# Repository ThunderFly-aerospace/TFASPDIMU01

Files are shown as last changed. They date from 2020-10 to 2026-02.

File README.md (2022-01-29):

# TFASPDIMU01 - sdp3x differental pressure sensor and IMU 9-axis unit



ThunderFly TFASPDIMU01 is SPI/I2C sensor board equipped with a differential pressure sensor (Senserion [SDP3x](https://www.sensirion.com/sdp3x/)) and 9-axis motion tracking sensor ([ICM-20948](https://invensense.tdk.com/products/motion-tracking/9-axis/icm-20948/)). Board is equipped with 7pin JST-GH connector. The sensor board is designed for multiple uses. It can be used as a self-adjusting anemometer [WINDGAUGE03](https://github.com/mlab-modules/WINDGAUGE03) or as an airspeed sensor for UAVs with optional function as the external magnetometer.

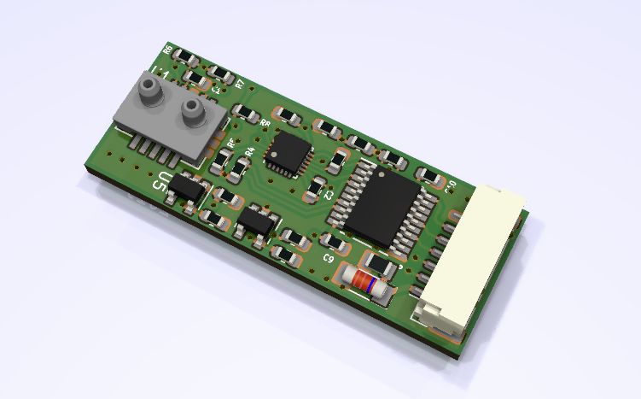
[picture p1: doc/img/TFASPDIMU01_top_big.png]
TFASPDIMU01 PCB


TFASPDIMU is commercially available from [ThunderFly s.r.o.](https://www.thunderfly.cz/), write an email to info@thunderfly.cz or shop at [Tindie store](https://www.tindie.com/stores/thunderfly/).

## Specification
 * Type: Differential and 9-axis motion sensor board
 * Mass: 3 g
 * Size: 36 x 14 mm
 * Power: +5 V
 * Connection: 7pin JST-GH connector, custom pinout

**SDP3x**
 * Range: +/- 125/500 Pa (depending on exact sensor type)
 * Excellent accuracy and repeatability, even below one Pascal
 * No zero-point offset, no temperature drift
 * Calibrated and temperature compensated
 * Fast sampling time of 2kHz at 16 bit resolution
 * I2C address: 0x21 (d33)

 **ICM-20948**
 * 3-axis gyroscope, 3-axis accelerometer, 3-axis compass (magnetometer)
 * Onboard Digital Motion Processor (DMP)
 * On-Chip 16-bit ADCs and Programmable Filters
 * 7 MHz SPI or 400 kHz Fast Mode I²C
 * Digital temperature sensor
 * Default I2C address: 0x68 (0d104), can be changed to 0x69 (0d105) by moving the resistor R2->R1. 

## Example of uses

### WINDGUAGE01

Ground control station anemometer [WINDGAUGE03](https://github.com/mlab-modules/WINDGAUGE03)

### TFSLOT01 - UAV airspeed sensor

Our [TFSLOT](https://github.com/ThunderFly-aerospace/TFSLOT01) senzor is an airspeed sensor for use mainly on UAV. Due to 3D printed case it is possible to optimalize part according to the location of sensor on UAV and tune their characteristics. First use of this sensor was on our autogyro [TF-G2](https://github.com/ThunderFly-aerospace/TF-G2/).

TFSLOT01 sensor

More details about this solution is available in the repository [TFSLOT01](https://github.com/ThunderFly-aerospace/TFSLOT01).

### TFPIPE01 - UAV airspeed sensor

Symmetric variant of TFSLOT sensor for different mounting options [TFPIPE01](https://github.com/ThunderFly-aerospace/TFPIPE01).

### TFVENTUFO - omnidirectional anemometer
This anemometer should also based on venturi effect. Thanks to an clever design, it will measure the wind speed from all directions (without knowing the direction).

### Angle of Attack sensor

In case of mounting on rotation slip-ring bearing the sensor could sense air [AoA of the vehicle](https://en.wikipedia.org/wiki/Angle_of_attack). Due to ability to turn in direction of airflow. The turnig direction could be sensed differentialy to position of aircraft by IMU embedded in the TFASPDIMU01 sensor. 

## Hardware

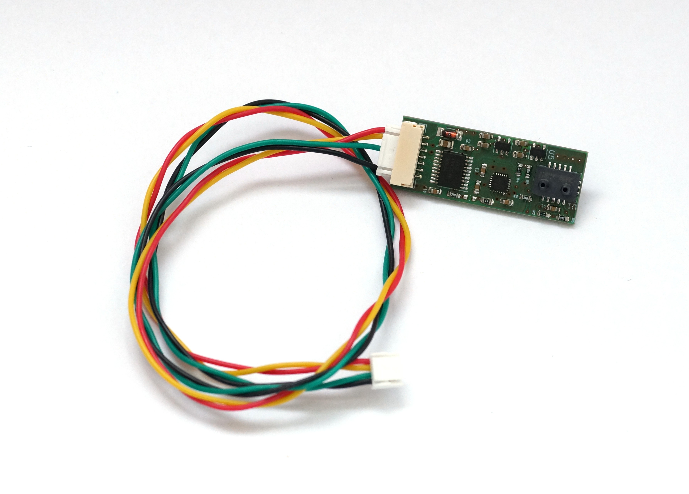
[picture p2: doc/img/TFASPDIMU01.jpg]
TFASPDIMU01 sensor


### Eletronic schema

Full schema is avialible in [PDF](/hw/sch_pcb/TFASPDIMU01.pdf)
schema

### Hardware layout

** IMG - technical draft **

### Pinout
|Pin #| I2C | SPI  |
| --- |:---:|:----:|
| 1 | +5V | +5V  |
| 2 | SCL | SCK  |
| 3 | --  | MISO |
| 4 | SDA | MOSI |
| 5 | --  | CS |
| 6 | INT | INT  |
| 7 | GND | GND  |
> Due to the possible wider use of the sensor, a standard pixhawk pinout is not used.

#### PixHawk autopilot cable

To increase the transmission quality, it is recommended to create pairs SDA,GND and SCL,+5V on the cable (as shown in image)

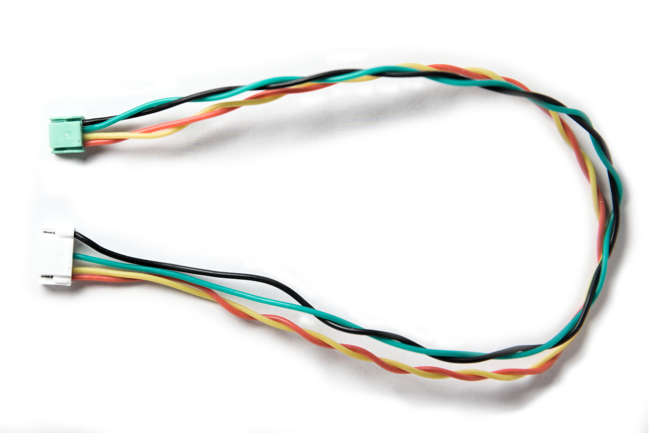
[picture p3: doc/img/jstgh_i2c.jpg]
I2C jstgh


| TFASPDIMU01 Pin | Sigal | Pixhawk | Color |
| ---:|:-----:|:---:|---|
| 1 | +5V |  1 | Red |
| 2 | SCL |  2 | Yellow|
| 4 | SDA |  3 | Green |
| 7 | GND |  4 | Black |
> Pixhawk pinout is listed according to the [Pixhawk connector standard](https://github.com/pixhawk/Pixhawk-Standards/blob/master/DS-009%20Pixhawk%20Connector%20Standard.pdf).

## Usage

### Python
For reading data from the sensor, we have prepared a python script in PyMLAB library that uses the pySMBus to readout data. It can be used directly from a computer with a corresponding converter (for example MLAB [USBI2C01A](https://wiki.mlab.cz/doku.php?id=cs:usbi2c)) or with one-board computers (Odroid, raspberry and similar) that have own smbus output.

#### Calibration vertification
Calibration can be verified by mounting of an anemometer to car roof and comparing it to speed obtained from GPS (gpsd). This needs to be done in windless weather.

### PX4
> We are now working on implementation of driver into PX4 stack.

Main usage of this sensor is as airspeed sensor. It can be also used as an external magnetometer and thermometer.

### Ardupilot
We are currently unable to implement the sensor in the Ardupilot flight stack. However, we will be happy to provide assistance with implementation. You can [contact us](https://www.thunderfly.cz/contact-us.html)

#### configuration
*TODO*

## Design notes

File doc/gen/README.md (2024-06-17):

# PCB

Board size: 36.0x14.0 mm (1.42x0.55 inches)

- This is the size of the rectangle that contains the board
- Thickness: 1.6 mm (63 mils)
- Material: FR4
- Finish: HAL
- Layers: 2
- Copper thickness: 35 µm

Solder mask: TOP / BOTTOM

- Color: Green

Silk screen: TOP / BOTTOM

- Color: White

# Important sizes

Clearance: 0.2 mm (8 mils)

Track width: 0.2 mm (8 mils)

- By design rules: 0.2 mm (8 mils)

Drill: 0.5 mm (20 mils)

- Vias: 0.5 mm (20 mils) [Design: 0.4 mm (16 mils)]
- Pads: 0.7 mm (28 mils)
- The above values are real drill sizes, they add 0.1 mm (4 mils) to plated holes (PTH)

Via: 0.8/0.4 mm (31/16 mils)

- By design rules: 0.8/0.3 mm (31/12 mils)
- Micro via: yes [0.2/0.1 mm (8/4 mils)]
- Buried/blind via: yes
- Total: 59 (thru: 59 buried/blind: 0 micro: 0)

Outer Annular Ring: 0.15 mm (6 mils)

- By design rules: 0.15 mm (6 mils)

Eurocircuits class: 4B
- Using min drill 0.5 mm for an OAR of 0.15 mm

# General stats

Components count: (SMD/THT)

- Top: 25/1 (SMD + THT)
- Bottom: 0/0 (NONE)

Defined tracks:

- 0.2 mm (8 mils)
- 0.25 mm (10 mils)
- 0.3 mm (12 mils)
- 0.4 mm (16 mils)
- 0.5 mm (20 mils)
- 0.6 mm (24 mils)
- 0.7 mm (28 mils)
- 0.8 mm (31 mils)

Used tracks:

- 0.2 mm (8 mils) (136) defined: yes
- 0.25 mm (10 mils) (72) defined: yes
- 0.3 mm (12 mils) (80) defined: yes
- 0.5 mm (20 mils) (53) defined: yes
- 0.6 mm (24 mils) (3) defined: yes

Defined vias:

- 0.8/0.4 mm (31/16 mils)

Used vias:

- 0.8/0.4 mm (31/16 mils) (Count: 59, Aspect: 2.0 A) defined: yes

Holes (excluding vias):

- 0.7 mm (28 mils) (3)

Oval holes:

Drill tools (including vias and computing adjusts and rounding):

- 0.5 mm (20 mils) (59)
- 0.7 mm (28 mils) (3)

Solder paste stats:

Using a paste with 87.75 % alloy, that has an specific gravity for the alloy of 7.4 g/cm³
and 1.0 g/cm³ for the flux. This paste has an specific gravity of  4.15 g/cm³.

The stencil thickness is  0.12 mm.

| Side | Pads with paste | Area [mm²] | Paste [g] |
|---|---|---|---|
| Total  | 121 | 89.25 | 0.44 |

Note: this is just an approximation to the theoretical value. Margins of the solder mask and waste aren't computed.

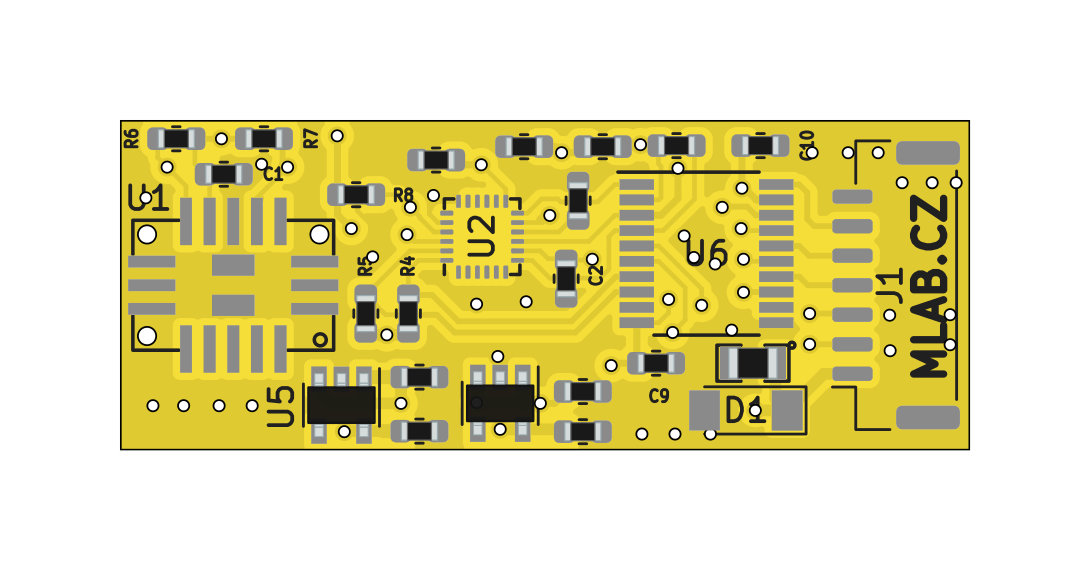
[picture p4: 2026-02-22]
doc/gen/img/TFASPDIMU01-top.png

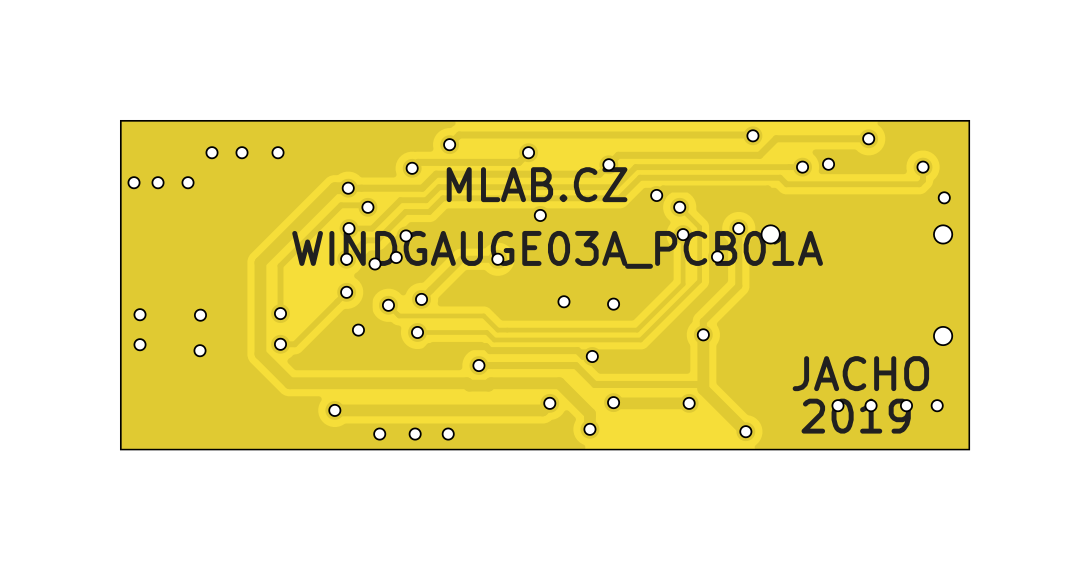
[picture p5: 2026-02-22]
doc/gen/img/TFASPDIMU01-bottom.png

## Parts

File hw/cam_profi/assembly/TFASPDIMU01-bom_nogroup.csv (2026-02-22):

Component | Description | Part | References | Value | Footprint | Quantity Per PCB | Datasheet | ust_id
1 | Unpolarized capacitor | C | C1 | 100nF | SMD-0603 | 1 | ~ | 5c70984712875079b91f8b4c
2 | Unpolarized capacitor | C | C10 | 100nF | SMD-0603 | 1 | ~ | 5c70984712875079b91f8b4c
3 | Unpolarized capacitor | C | C2 | 100nF | SMD-0603 | 1 | ~ | 5c70984712875079b91f8b4c
4 | Unpolarized capacitor | C | C3 | 100nF | SMD-0603 | 1 | ~ | 5c70984712875079b91f8b4c
5 | Unpolarized capacitor | C | C4 | 100nF | SMD-0603 | 1 | ~ | 5c70984712875079b91f8b4c
6 | Unpolarized capacitor | C | C9 | 100nF | SMD-0603 | 1 | ~ | 5c70984712875079b91f8b4c
7 | Unpolarized capacitor | C | C5 | 1uF | SMD-0603 | 1 | ~ | 5c70984712875079b91f8b50
8 | Unpolarized capacitor | C | C6 | 1uF | SMD-0603 | 1 | ~ | 5c70984712875079b91f8b50
9 | Unpolarized capacitor | C | C7 | 1uF | SMD-0603 | 1 | ~ | 5c70984712875079b91f8b50
10 | Unpolarized capacitor | C | C8 | 1uF | SMD-0603 | 1 | ~ | 5c70984712875079b91f8b50
11 | Unpolarized capacitor | C | C11 | 10uF | SMD-0805 | 1 | ~ | 5c70984812875079b91f8bbd
12 | Diode | D | D1 | BZV55C-5,6V | D_MiniMELF | 1 | ~ | 5c70984512875079b91f88b1
13 | 1x08 2.54 mm pitch header | SM07B-GHS-TB | J1 | SM07B-GHS-TB | JST_GH_SM07B-GHS-TB_1x07-1MP_P1.25mm_Horizontal | 1 |  | 5c7250081287500b4e112e78
14 | Resistor | R | R2 | 0R | SMD-0603 | 1 | ~ | 5c70984512875079b91f896b
15 | Resistor | R | R4 | 10k | SMD-0603 | 1 | ~ | 5c70984612875079b91f899f
16 | Resistor | R | R5 | 10k | SMD-0603 | 1 | ~ | 5c70984612875079b91f899f
17 | Resistor | R | R6 | 10k | SMD-0603 | 1 | ~ | 5c70984612875079b91f899f
18 | Resistor | R | R7 | 10k | SMD-0603 | 1 | ~ | 5c70984612875079b91f899f
19 | Resistor | R | R8 | 10k | SMD-0603 | 1 | ~ | 5c70984612875079b91f899f
20 | Resistor | R | R9 | 10k | SMD-0603 | 1 | ~ | 5c70984612875079b91f899f
21 | Resistor | R | R1 | - | SMD-0603 | 1 | ~
22 | InvenSense 9-Axis Motion Sensor, Accelerometer, Gyroscope, Compass, I2C/SPI, QFN-24 | ICM-20948 | U2 | ICM-20948 | InvenSense_QFN-24_3x3mm_P0.4mm | 1 | http://www.invensense.com/wp-content/uploads/2016/06/DS-000189-ICM-20948-v1.3.pdf | 5c725a431287500b4e112ef5
23 | 300mA Low-dropout Voltage Regulator, Vout 1.8V, Vin up to 5.5V, SOT-23 | MIC5504-1.8YM5 | U5 | MIC5504-1.8YM5-TR | SOT-23-5 | 1 | http://ww1.microchip.com/downloads/en/DeviceDoc/MIC550X.pdf | 5c7256781287500b4e112eba
24 | 300mA Low-dropout Voltage Regulator, Vout 3.3V, Vin up to 5.5V, SOT-23 | MIC5504-3.3YM5 | U4 | MIC5504-3.3YM5-TR | SOT-23-5 | 1 | http://ww1.microchip.com/downloads/en/DeviceDoc/MIC550X.pdf | 5c7255e81287500b4e112ea2
25 |  | SDP3x | U1 | SDP3x | SDP3x | 1 |  | 5c70984812875079b91f8bd0
26 | Bidirectional level-shifting voltage translator, TSSOP-20 | TXS0108EPW | U6 | TXS0108EPW | TSSOP-20_4.4x6.5mm_P0.65mm | 1 | www.ti.com/lit/ds/symlink/txs0108e.pdf | 5c7258471287500b4e112edd

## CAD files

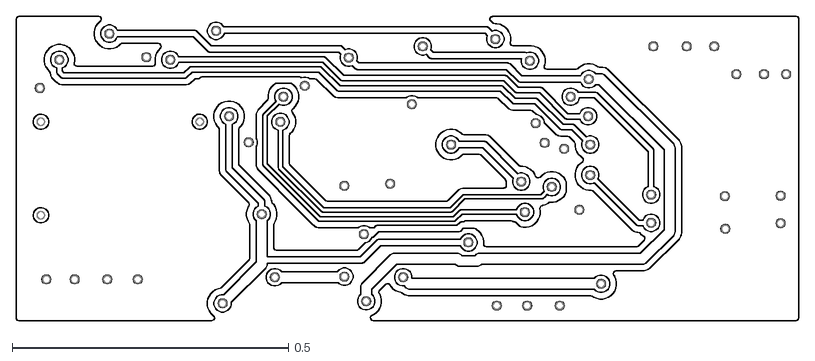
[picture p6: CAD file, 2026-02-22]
doc/gen/dxf/TFASPDIMU01-B_Cu.dxf
1.42 x 0.55

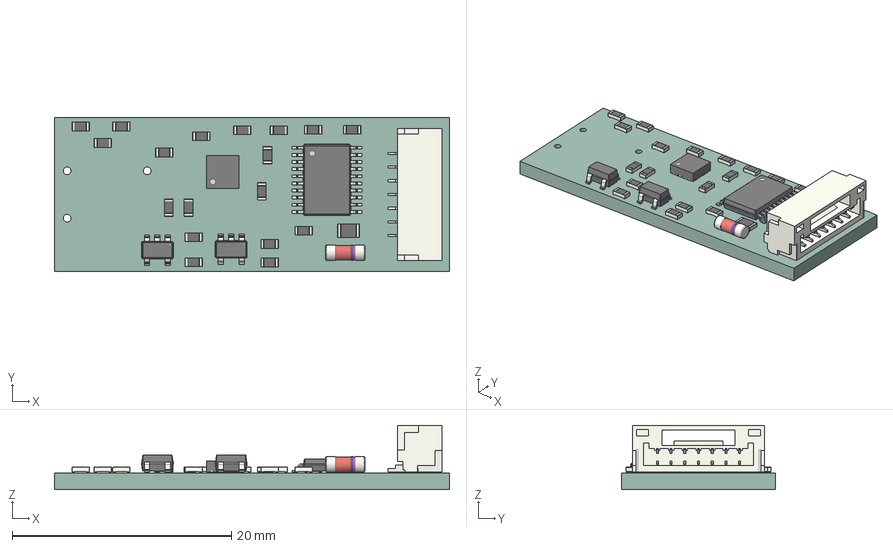
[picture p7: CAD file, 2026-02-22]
doc/gen/TFASPDIMU01.step
36.0 x 14.0 x 5.84 mm
R_0603_1608Metric x 18
QFN-24-1EP_3x3mm_P0.4mm_EP1.75x1.6mm
D_MiniMELF
TSSOP-20_4.4x6.5mm_P0.65mm
JST_GH_SM07B-GHS-TB_1x07-1MP_P1.25mm_Horizontal
SOT-23-5 x 2
R_0805_2012Metric
kibot_vu3v6cgv_PCB

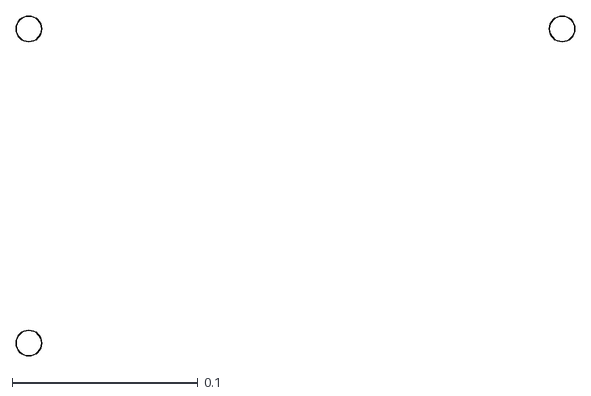
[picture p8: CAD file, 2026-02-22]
doc/gen/dxf/TFASPDIMU01-B_Courtyard.dxf
0.301 x 0.183

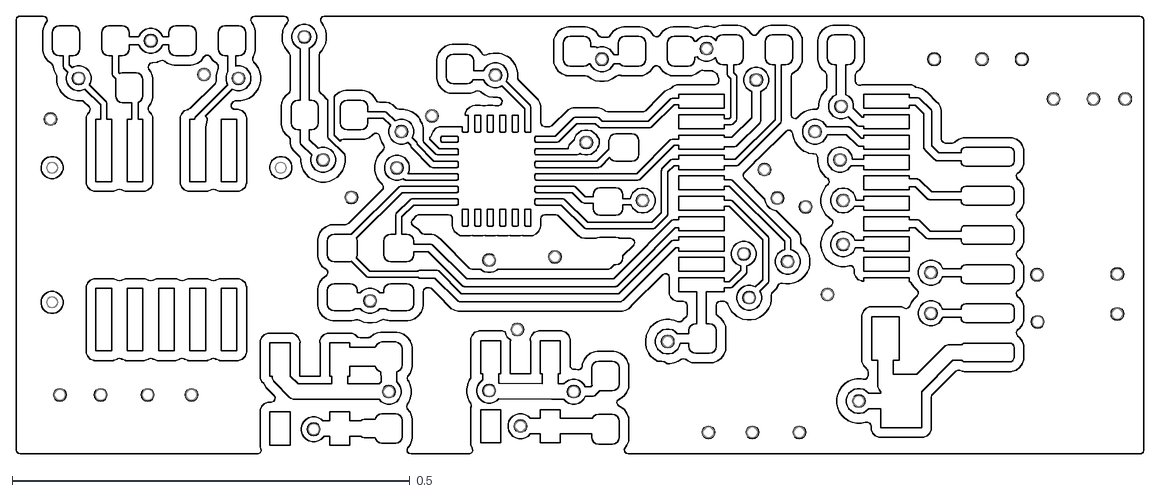
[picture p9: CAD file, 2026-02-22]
doc/gen/dxf/TFASPDIMU01-F_Cu.dxf
1.42 x 0.55

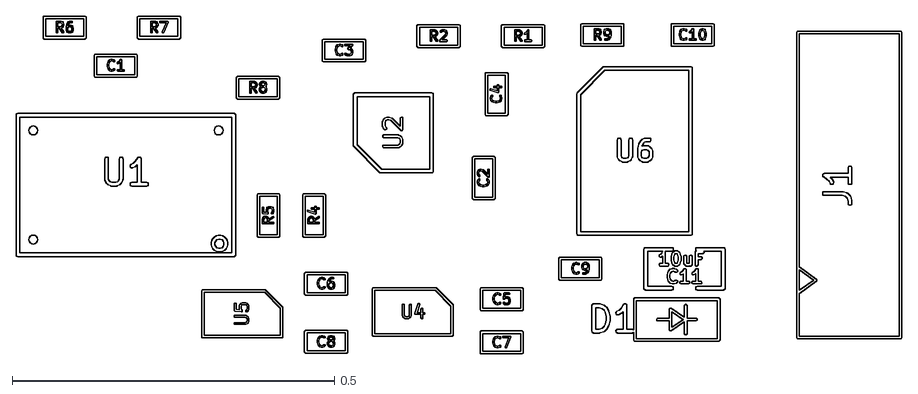
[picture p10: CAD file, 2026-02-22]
doc/gen/dxf/TFASPDIMU01-F_Fab.dxf
1.37 x 0.524

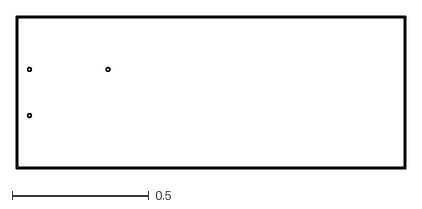
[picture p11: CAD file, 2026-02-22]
doc/gen/dxf/TFASPDIMU01-Edge_Cuts.dxf
1.42 x 0.557

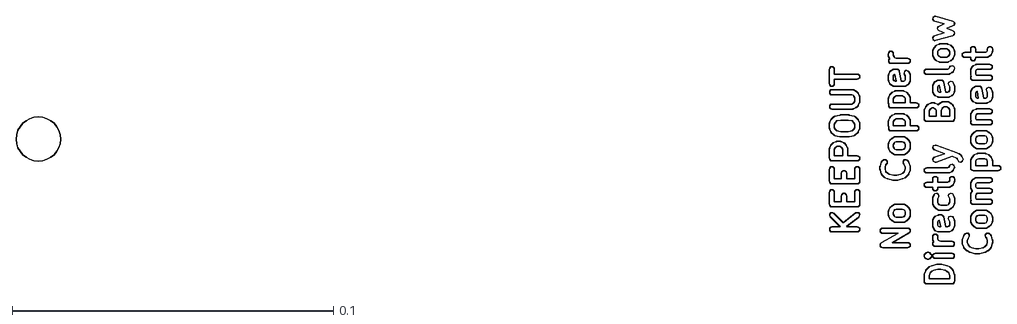
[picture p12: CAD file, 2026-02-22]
doc/gen/dxf/TFASPDIMU01-User_Comments.dxf
0.307 x 0.0833

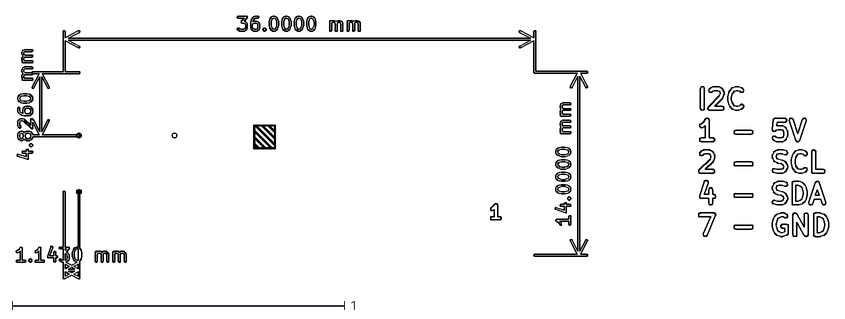
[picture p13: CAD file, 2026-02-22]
doc/gen/dxf/TFASPDIMU01-User_Drawings.dxf
2.45 x 0.791

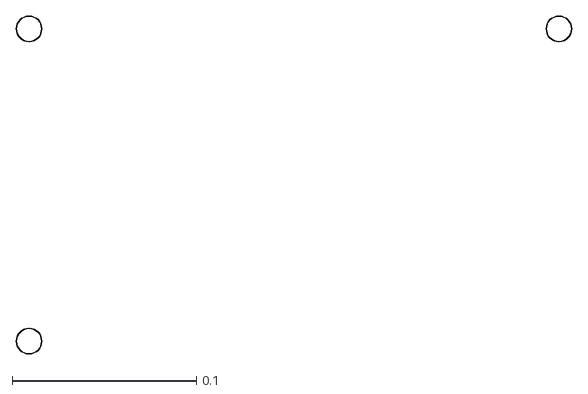
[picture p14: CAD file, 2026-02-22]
doc/gen/dxf/TFASPDIMU01-F_Adhesive.dxf
0.301 x 0.183

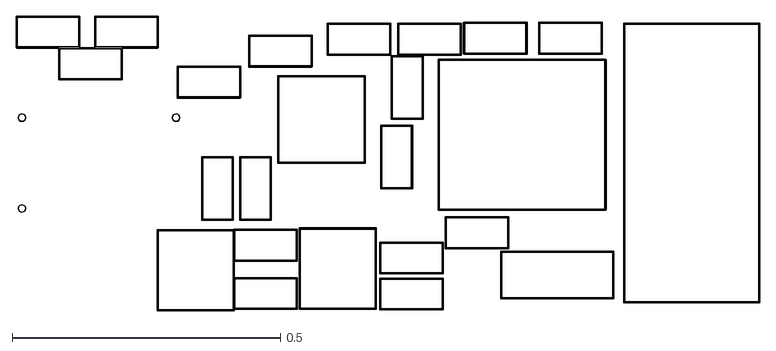
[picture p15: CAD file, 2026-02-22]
doc/gen/dxf/TFASPDIMU01-F_Courtyard.dxf
1.39 x 0.549

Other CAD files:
doc/gen/dxf/TFASPDIMU01-B_Mask.dxf
doc/gen/dxf/TFASPDIMU01-B_Silkscreen.dxf
doc/gen/dxf/TFASPDIMU01-F_Mask.dxf
doc/gen/dxf/TFASPDIMU01-F_Paste.dxf
doc/gen/dxf/TFASPDIMU01-F_Silkscreen.dxf

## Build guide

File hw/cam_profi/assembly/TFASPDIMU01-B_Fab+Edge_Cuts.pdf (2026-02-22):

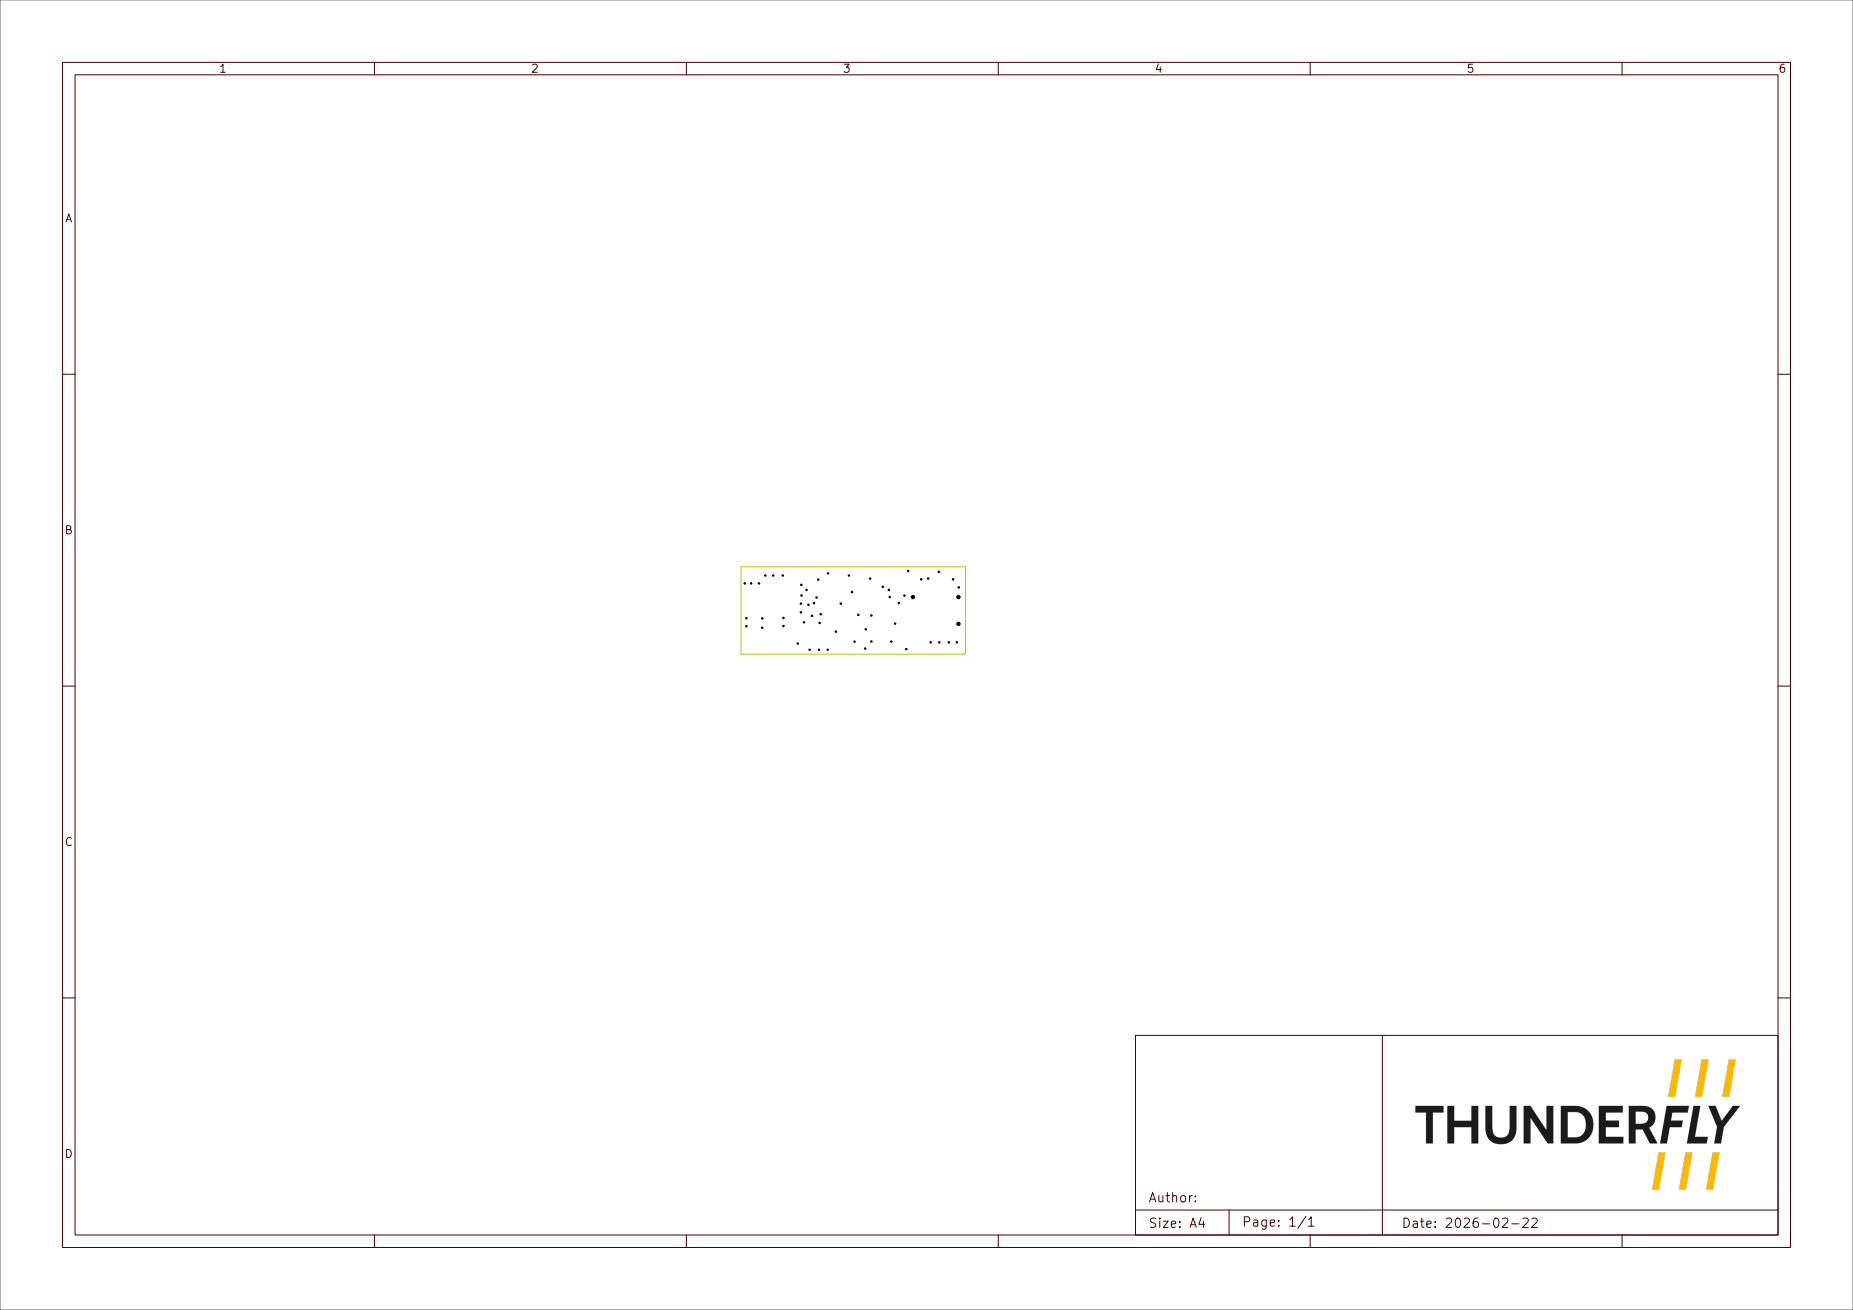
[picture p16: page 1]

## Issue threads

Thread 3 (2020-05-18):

Implementation of airspeed sensor based on venturi pipe into PX4 firmware

kaklik, 2020-05-18:
Snímač odvozený z anemometru by nyní bylo potřeba implementovat do PX4 firmware.  Což by znamenalo založit nový driver v PX4 (odvozením od současného [driveru SPD33](https://github.com/ThunderFly-aerospace/PX4Firmware/tree/master/src/drivers/differential_pressure/sdp3x)), který bude rozšířen o inicializaci toho [IMU čipu](https://github.com/PX4/Firmware/tree/master/src/drivers/imu/icm20948) tak, aby bylo možné číst data přímo z tlakového senzoru.   [Vyčítat IMU data z IMC-20948](https://github.com/PX4/Firmware/tree/master/src/drivers/imu/icm20948) budeme v případě airspeed senzoru řešit později, až bude využit k měření úhlu náběhu.

roman-dvorak, 2020-10-29:
Další použití IMU jednotky je jako externí magnetometr při pevném připevnění senzoru.

kaklik, 2021-01-13:
V PX4 [plánují změny](https://github.com/PX4/PX4-Autopilot/pull/15853), které se zřejmě týkají tohoto řešení.

dagar, 2021-01-13:
Let me know if you have any questions about the direction of drivers in PX4. In general the plan is make the actual drivers as simple as possible, only publishing raw data via uORB. All processing (calibration, filtering, etc) will be done downstream.

slimonslimon, 2021-01-28:
@dagar thank you for your interest! Your advice is welcomed!

We are using this PCB in https://github.com/ThunderFly-aerospace/TFSLOT01 so, primarily  we need tp get diff pressure sensor to work.

These days we have only simple (dummy) driver for icm20948 connected over i2c - it's only enable bridging of I2C buss https://github.com/ThunderFly-aerospace/PX4Firmware/tree/tfaspdimu01/src/drivers/imu/invensense/icm20948i2c So we can use original sdp3xx driver of diff pressure sensor.

But The question is, how to update original icm20948 driver (now SPI only, i think) to be able to work on I2C?
Or do you have other opinion on implementing these kind of drivers? (And drivers for i2c devices on some secondary/slave bus after other device? - or this is so unusual that is better to copy the driver like https://github.com/ThunderFly-aerospace/PX4Firmware/blob/tfaspdimu01/src/drivers/imu/invensense/icm20948/ICM20948_AK09916.cpp) ?

slimonslimon, 2021-01-28:
I think our PCB not support SPI. @kaklik ?

kaklik, 2021-01-28:
> I think our PCB does not support SPI. @kaklik ?

Yes, it supports it, the [TFASPDIMU01](https://github.com/ThunderFly-aerospace/TFASPDIMU01) design accept SPI connection also. It is supposed that SPI to be used in some applications requiring high-rate readout like Angle of Attack sensors for example.

dagar, 2021-02-02:
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

I was going to do a dummy icm20948 that simply enables i2c passthru because I don't think the IMU is all that useful on I2C. We can still add it if someone wants it though.

roman-dvorak, 2021-05-16:
New passtrought driver `icm20948_i2c_passthrough` from @dagar  (https://github.com/ThunderFly-aerospace/PX4Firmware/commit/ad934b49116afd6e615742c108d0ebfa90db05b3) solve problem how to connect TFSLOT to PX4 autopilot and how to route SDP3x I2C trought icm20948.

[ASPDIMU01](https://github.com/ThunderFly-aerospace/TFASPDIMU01) sensor board modul has the default icm20948 address 0x68. Driver assumes address 0x69 (connected addr0 to vcc). Therefore, jumper needs to be replaced from position `R2` (gnd) -> `R1`(vcc). Then the driver starts itself, including airspeed measurements.

It was tested with current PX4/master (from QGC).

To complete support of TFSLOT in PX4, we need to solve this issue: https://github.com/PX4/PX4-Autopilot/issues/17576
While solving this issue, I found this bug https://github.com/PX4/PX4-Autopilot/issues/17579

kaklik, 2021-09-04:
> Let me know if you have any questions about the direction of drivers in PX4. In general, the plan is to make the actual drivers as simple as possible, only publishing raw data via uORB. All processing (calibration, filtering, etc) will be done downstream.

Hi @dagar,
I have a question about the general approach of drivers - how to handle corrupted transfers on the I²C bus?
In the current situation, we experiencing issues with the SDP33 sensor.
The sensor in every test flight reports `NaN` after a while.
 At the beginning of resolving that issue, we supposed it is a hardware issue in [TFASPDIMU01](https://github.com/ThunderFly-aerospace/TFASPDIMU01) circuit. Therefore we made a new version [TFASPDIMU02](https://github.com/ThunderFly-aerospace/TFASPDIMU02) with significantly increased physical robustness of the I²C bus.
Unfortunately, the failure behavivour of the sensor did not change noticeably.

According to recent measurements made by an oscilloscope, I am almost sure, that situation is not primarily a hardware issue.  The SDA and SCL signals are sharp and look good even after the failure of the SDP33 sensor. The PX4 reportedly continues in the reading of the ICM20948 magnetometer. But at the same time as SDP33 failure, the logs contain a "stopping compass use!" message.

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

To debug the issue I looked into [SDP3X  driver](https://github.com/PX4/PX4-Autopilot/blob/master/src/drivers/differential_pressure/sdp3x/SDP3X.cpp) and I found that the driver never calls an SDP sensor reset. Therefore it is possible that the SDP33 sensor hangs by a single corrupted I²C transfer (which cannot be simply caught by oscilloscope). But the driver is not capable to resolve that.
That corresponds to the behavior that airspeed readout recovers only after the power cycle of the autopilot.  Software reboot does not bring up SDP33 back.

dagar, 2021-09-06:
Hi @kaklik,

In general I try to have each driver monitor itself and be able to fully reset and reinitialize if anything goes wrong. The SDP3X is a bit of an annoying case because it only responds to a general call reset, which potentially impacts other things on the same bus.

Can you take a look at this PR to see if it helps? https://github.com/PX4/PX4-Autopilot/pull/18085/files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

kaklik, 2021-09-07:
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

Ok, I have performed a simple ground test and I am able to get error from the airspeed sensor:

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

Actually, I do not quickly know where the `DEVICE_DEBUG("alone on the bus, issuing general call reset");` message should be issued to check that sensor was actually attempted to reset.

But the sdp3x_airspeed driver is running after the failure:

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

Could be stopped and started again
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

But the airspeed value does not bring back in QGC again.   The new situation is that PX4 software reboot gets the airspeed sensor back. It seems to be an improvement. :)

kaklik, 2021-09-08:
Recently @roman-dvorak  found in log files, that the `differentiall_pressure` message is actually logged even after airspeed_sensor failure.

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

The root of the problem probably is that the airspeed sensor is marked as invalid, after a while of flight.

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

kaklik, 2022-01-02:
The main goal of this issue - seamless integration of the sensor to PX4 firmware is already resolved. The sensor is additionally able to work as an external magnetometer.  The next features like

- Ability to adopt different possible TFSLOT geometries (airfoils)
- Ability to detect airframe vibrations (flutter)
- Angle of attack sensing

will be resolved in the future, after some demand will develop (if any).  The additional discussion is already moved to PX4 PR: https://github.com/PX4/PX4-Autopilot/pull/18593

Closed 2022-01-02.

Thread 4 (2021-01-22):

Nelze změnit I2C adresa u SDP3x sezoru

roman-dvorak, 2021-01-22:
SDP3x má addr pin přímo připojený do GND, Díky tomu nelze změnit I2C adresa SDP3x senzoru. Je to trochu komplikace v případě, že se v IMU jednotce nastaví mostování I2C (např kvůli nastavení senzoru). A na sběrnici je připojený jiný SDP3x senzor se stejnou adresou.

kaklik, 2021-02-26:
Adresa se nastavuje velikostí rezistoru z ADDR pinu do GND, podle tabulky z datasheetu:

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

ChroustJan, 2021-08-02:
@roman-dvorak kolik adres by jsme chtěli? 2 nebo 3?

kaklik, 2021-08-04:
Vyřešeno v [nové verzi](https://github.com/ThunderFly-aerospace/TFASPDIMU02).

Closed 2021-08-04.

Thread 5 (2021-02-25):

Oscilace signálů při zatížení větší kapacitou - délkou vodičů

kaklik, 2021-02-25:
Tak pokud se zapojí TFSLOT do série s TFRPM tak se s docela velkou pravděpodobností na SDA stane tohle (za pozornost stojí zejména to, že generované obdélníky jsou na 6 MHz, tedy naprosto mimo pásmo běžné I2C signalizace):

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

Vznikne to následující sekvencí příkazů:

    icm20948i2c start -X -b 4

V tomto okamžiku je sběrnice ještě v pořádku. Rozbije se až následujícím příkazem:

    sdp3x_airspeed start  -X

Pokud se TFASPDIMU odpojí a připojí zpátky, tak se sběrnice zotaví a jsou na ní normální data.

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

Pokud se k autopilotovi připojí pouze TFASPDIMU na krátké dráty (15cm), tak I2C  částečně funguje. Zákmity vznikají jen mezi bity, kdy je sběrnice zřejmě buzena pouze pull-upy.

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

Jedná se tak zjevně o HW problém.

_Originally posted by @kaklik in https://github.com/ThunderFly-aerospace/TF-G2/issues/88#issuecomment-786179307_

kaklik, 2021-02-25:
Příčinou problému je obvod [TXS0108E](https://www.ti.com/lit/ds/symlink/txs0108e.pdf), který obsahuje  "one shot accerator", který zrychluje náběžnou hranu připojením push-pull budiče na dobu 30ns.

Konstrukce tak narazila na limitaci v jeho datasheetu. "TI recommendsthatthis lumped-loadcapacitanceisconsideredin orderto avoidone-shotretriggering,bus contention,outputsignaloscillations,or otheradversesystem-levelaffects"

Tento obvod ale bohužel nejde deaktivovat. Takže jediné řešení zřejmě je najít nějakou náhradu, která se aktivně nesnaží o zrychlování signálových hran.

kaklik, 2021-02-26:
Tak jsem zjistil, že zákmity mají největší amplitudu na vnější I2C sběrnici směrem do autopilota, jak je ostatně vidět i na obrázku výše.

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

Zkusil jsem proto do série s konektorem na vnější sběrnici zapojit rezistor 82 Ohm.

Zákmity tím úplně zmizely.

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

Stejnou úpravu je zřejmě potřebné udělat na všech výstupních vodičích.  Hodnota 82 Ohm je zvolena náhodně jako hodnota rezistoru, který jsem měl zrovna k dispozici, je poměrně pravděpodobné, že bude stačit hodnota menší. Například 33 Ohm.

kaklik, 2021-06-09:
Dnes jsem testoval zda [TFI2CEXT01](https://github.com/ThunderFly-aerospace/TFI2CEXT01). Je náhradou za přidání tlumících rezistorů z komentáře https://github.com/ThunderFly-aerospace/TFASPDIMU01/issues/5#issuecomment-786612154

Výsledkem je, že není. V případě použití v kombinaci s [USBI2C01A](https://www.mlab.cz/module/USBI2C01A) se situace dokonce zhorší. Z pohledu software se situace projevuje tak, že [program](https://github.com/MLAB-project/pymlab/blob/dev/examples/windgauge03a_example.py) přečte náhodné ID z čipu SDP33, který v důsledku toho správně neidentifikuje. Následně se rozpadne celá komunikace na chybu "I2C Error".
Spuštění programu lze vzápětí opakovat se stejným výsledkem (Ale obvykle jiným ID SDP33).

Stejný kus TFASPIDIMU při připojení přes [TFRPM01](https://github.com/ThunderFly-aerospace/TFRPM01/) funguje normálně. (Bez změny osazených součástek oproti stavu z výroby).
Avšak při přidání TFI2CEXT01 před TFASPIDIMU opakovatelně přestane fungovat.

U autopilota CUAV V5+ je však situace jiná. Zde  [TFI2CEXT01](https://github.com/ThunderFly-aerospace/TFI2CEXT01) zřejmě nějakým způsobem pomáhá, neboť je možné spolehlivě provozovat TFASPIDIMU připojený přes 30cm kablík k TFI2CEXT01 a následně do autopilota přes ~15cm kablík. Tudíž například toto je funkční sestava:

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

V případě autopilota ale testování komplikuje zatím neopravený [bug v PX4](https://github.com/PX4/PX4-Autopilot/issues/17579), který způsobuje že pro testování s autopilotem je potřeba v  TFASPIDIMU přehodit rezistor z pozice R1 na pozici R2. (Aby se změnila adresa čipu icm20948i2c na 0x69, kterou má autopilot hardcodovanou). V důsledku toho byl s autopilotem otestován pouze jeden kus TFASPIDIMU, který má [odebrány všechny pullupy](https://github.com/ThunderFly-aerospace/TFASPDIMU01/issues/6) a přidány tlumící sériové rezistory 62 Ohm na externí SDA a SCL signály.

Ve všech zde popisovaných případech jsem na osciloskopu kontroloval signály SDA a SCL. Průběhy byly velmi hranaté bez morfologických znaků, ze kterých by bylo možné vysvětlit nefunkčnost v popisovaných případech.

Kromě nefunkčního stavu v kombinaci s TFI2CEXT01 jsem ještě narazil na celkem tři kusy TFASPIDIMU, které nefungovaly  v žádné situaci. U nich předpokládám, že mají nějaké HW výrobní chyby.

kaklik, 2021-06-22:
Tak tři nefunkční kusy měly na sobě výrobní vady vesměs způsobené špatným zaletováním na různých místech. Nejčastěji u IO.

Dále podle [tohoto dokumentu](https://www.ti.com/lit/an/scea060/scea060.pdf). Použitý translátor série TXS vůbec nemá výstupní buffer. Jeho vnitřní zapojení odpovídá tomuto schéma:

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

Od takto konstruovaného translátoru asi nelze očekávat, že bude fungovat dobře v kombinaci s dlouhým vedením. Neboť to znamená, že koncové zařízení v tomto případě snímače [SDP33](https://docs.rs-online.com/3cff/0900766b81643b7b.pdf) stáhne celé vedení na logickou nulu i včetně všech parazitních zátěží. Proudová zatížitelnost ani napěťové rozhodovací úrovně však v datasheetu Sensirionu nejsou specifikovány. Nelze tak určit zda primární problém není přetížení těchto pinů.
V každém případě by to zřejmě chtělo v další verzi tuto část vyřešit jinak. Ideálně za použití bufferu, který bude oddělovat vnitřní a vnější sběrnici, aby od čidel na desce nebyla vyžadována schopnost utáhnout celou délku sběrnice.

kaklik, 2021-08-01:
Vzhledem  k aktuální situaci, kdy se ani po několika pokusech nepodařilo vyřešit kmitání signálu změnou rezistorů. Zároveň se mi nepodařilo najít žádný translator, který by uměl jak SPI tak i I2C sběrnici.
Navrhoval bych proto možnost připojení na SPI u TFASPDIMU zrušit.  Místo toho vytvořit variantu pouze s I2C konektorem podle Pixhawk standardu.

I2C vyvést ven z plošného spoje pomocí obvodu [PCA9509](https://cz.mouser.com/datasheet/2/302/PCA9509P-1127567.pdf), který našel @roman-dvorak  nebo případně pomocí obvodu [PCA9617A](https://www.nxp.com/docs/en/data-sheet/PCA9617A.pdf), který by měl být lepší a umožňovat větší zatížení sběrnice, ale zároveň je zřejmě hůře dostupný.

Při odstranění současného translátoru zůstává otázkou, jak se vypořádat s připojením I2C na senzor SDP33.  Jeho připojení přímo na externí sběrnici asi není vhodné, kvůli celkové odolnosti zařízení.  Zároveň ale ICM-20948, má logické úrovně 1.8V a u SDP3x není bohužel napsáno, jaké logické úrovně vyžaduje.    Je tak možné buď vyzkoušet připojení na 1.8V logiku a ověřit, že komunikace funguje. Nemusí to však být řešení funkční přes celý výrobní rozptyl senzorů SDP3x.  Je tak možná lepší postupovat konzervativně a mezi  ICM-20948 a SDP3x dát ještě jiný napěťový translator na I2C.  Nevýhodou takového řešení je, že DPS pak asi nebude možné výrazně zmenšit.

slimonslimon, 2021-08-02:
Co se podívat jak to řeší konkurence která nabízí spd3xx jen jako rychlosní senzor PX4 ?

ChroustJan, 2021-08-02:
@kaklik nedá se někam napsat na podporu?  Jinak já taky definici nenašel.

kaklik, 2021-09-04:
Problém je technicky vyřešený v nové verzi [TFASPDIMU02](https://github.com/ThunderFly-aerospace/TFASPDIMU02)

Closed 2021-09-04.

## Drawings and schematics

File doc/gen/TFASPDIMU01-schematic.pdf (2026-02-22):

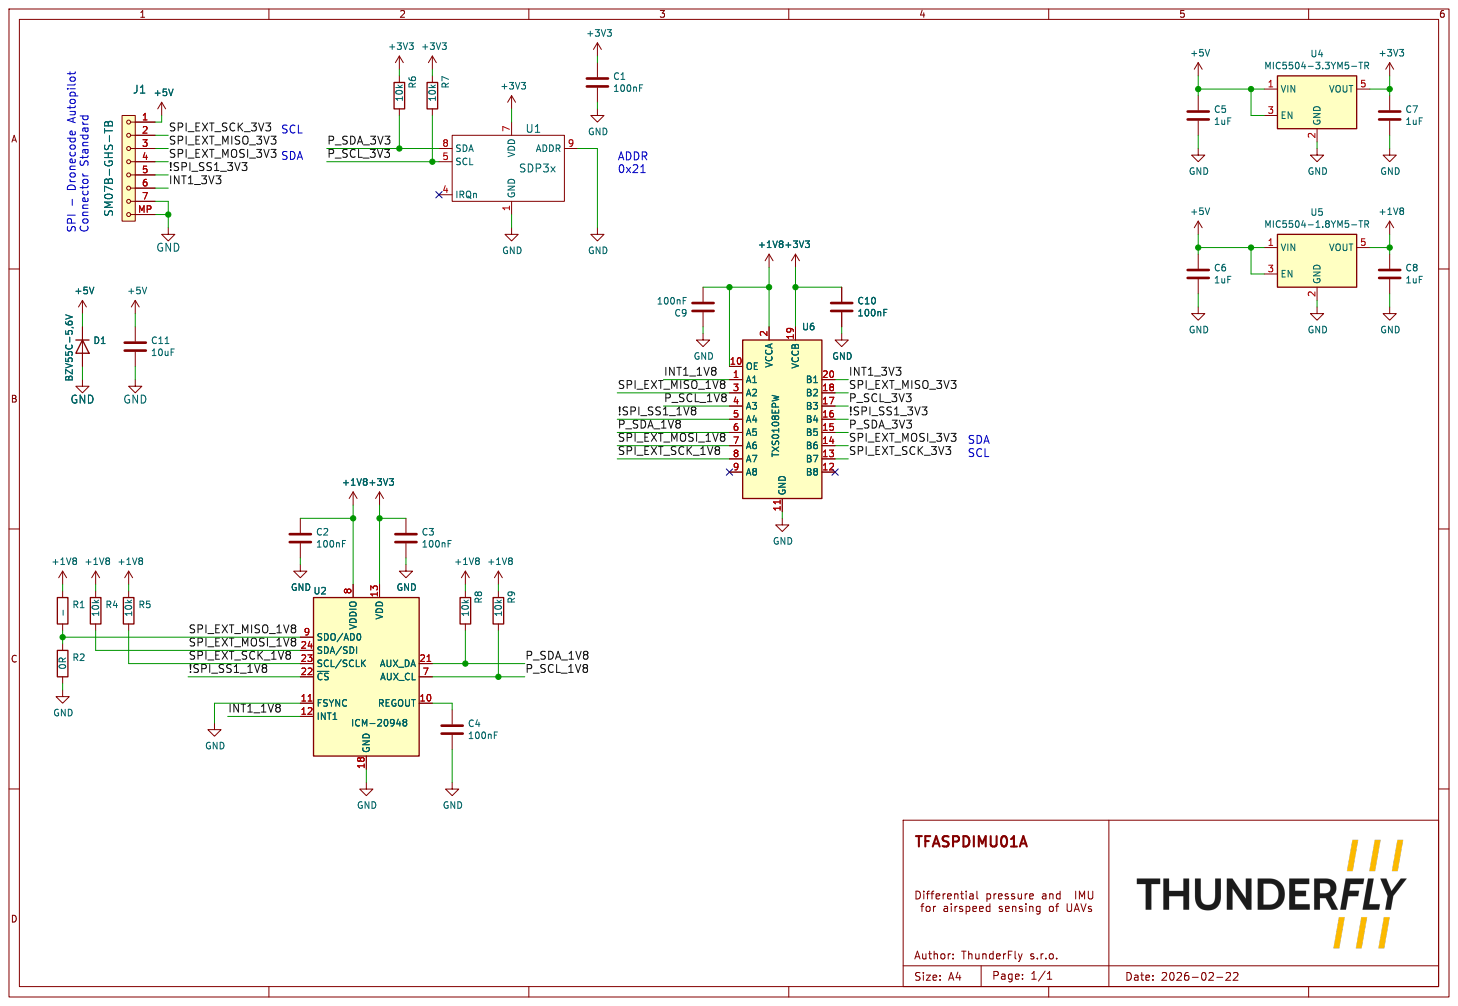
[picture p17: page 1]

0x21 SPI - Dronecode Autopilot Connector Standard

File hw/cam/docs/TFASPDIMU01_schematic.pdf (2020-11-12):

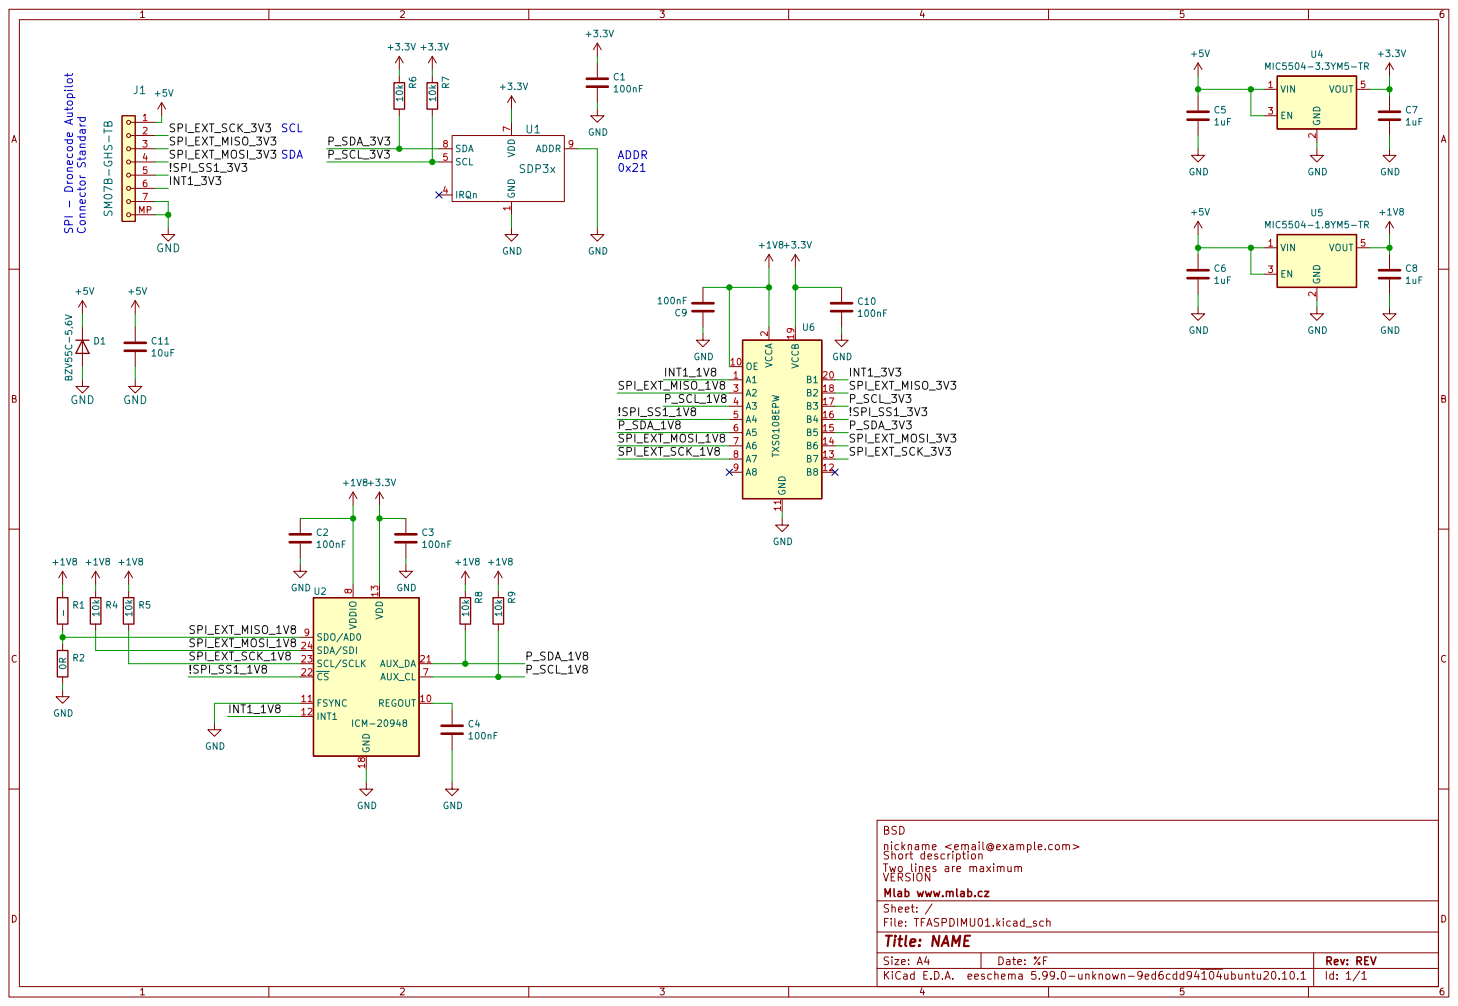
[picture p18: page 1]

2 EN 3 VOUT 5 U4 MIC5504-3.3YM5-TR GND
J1 SM07B-GHS-TB

nickname <email@example.com> BSD

Short description
File: TFASPDIMU01.kicad_sch Sheet: / Mlab www.mlab.cz VERSION

Two lines are maximum

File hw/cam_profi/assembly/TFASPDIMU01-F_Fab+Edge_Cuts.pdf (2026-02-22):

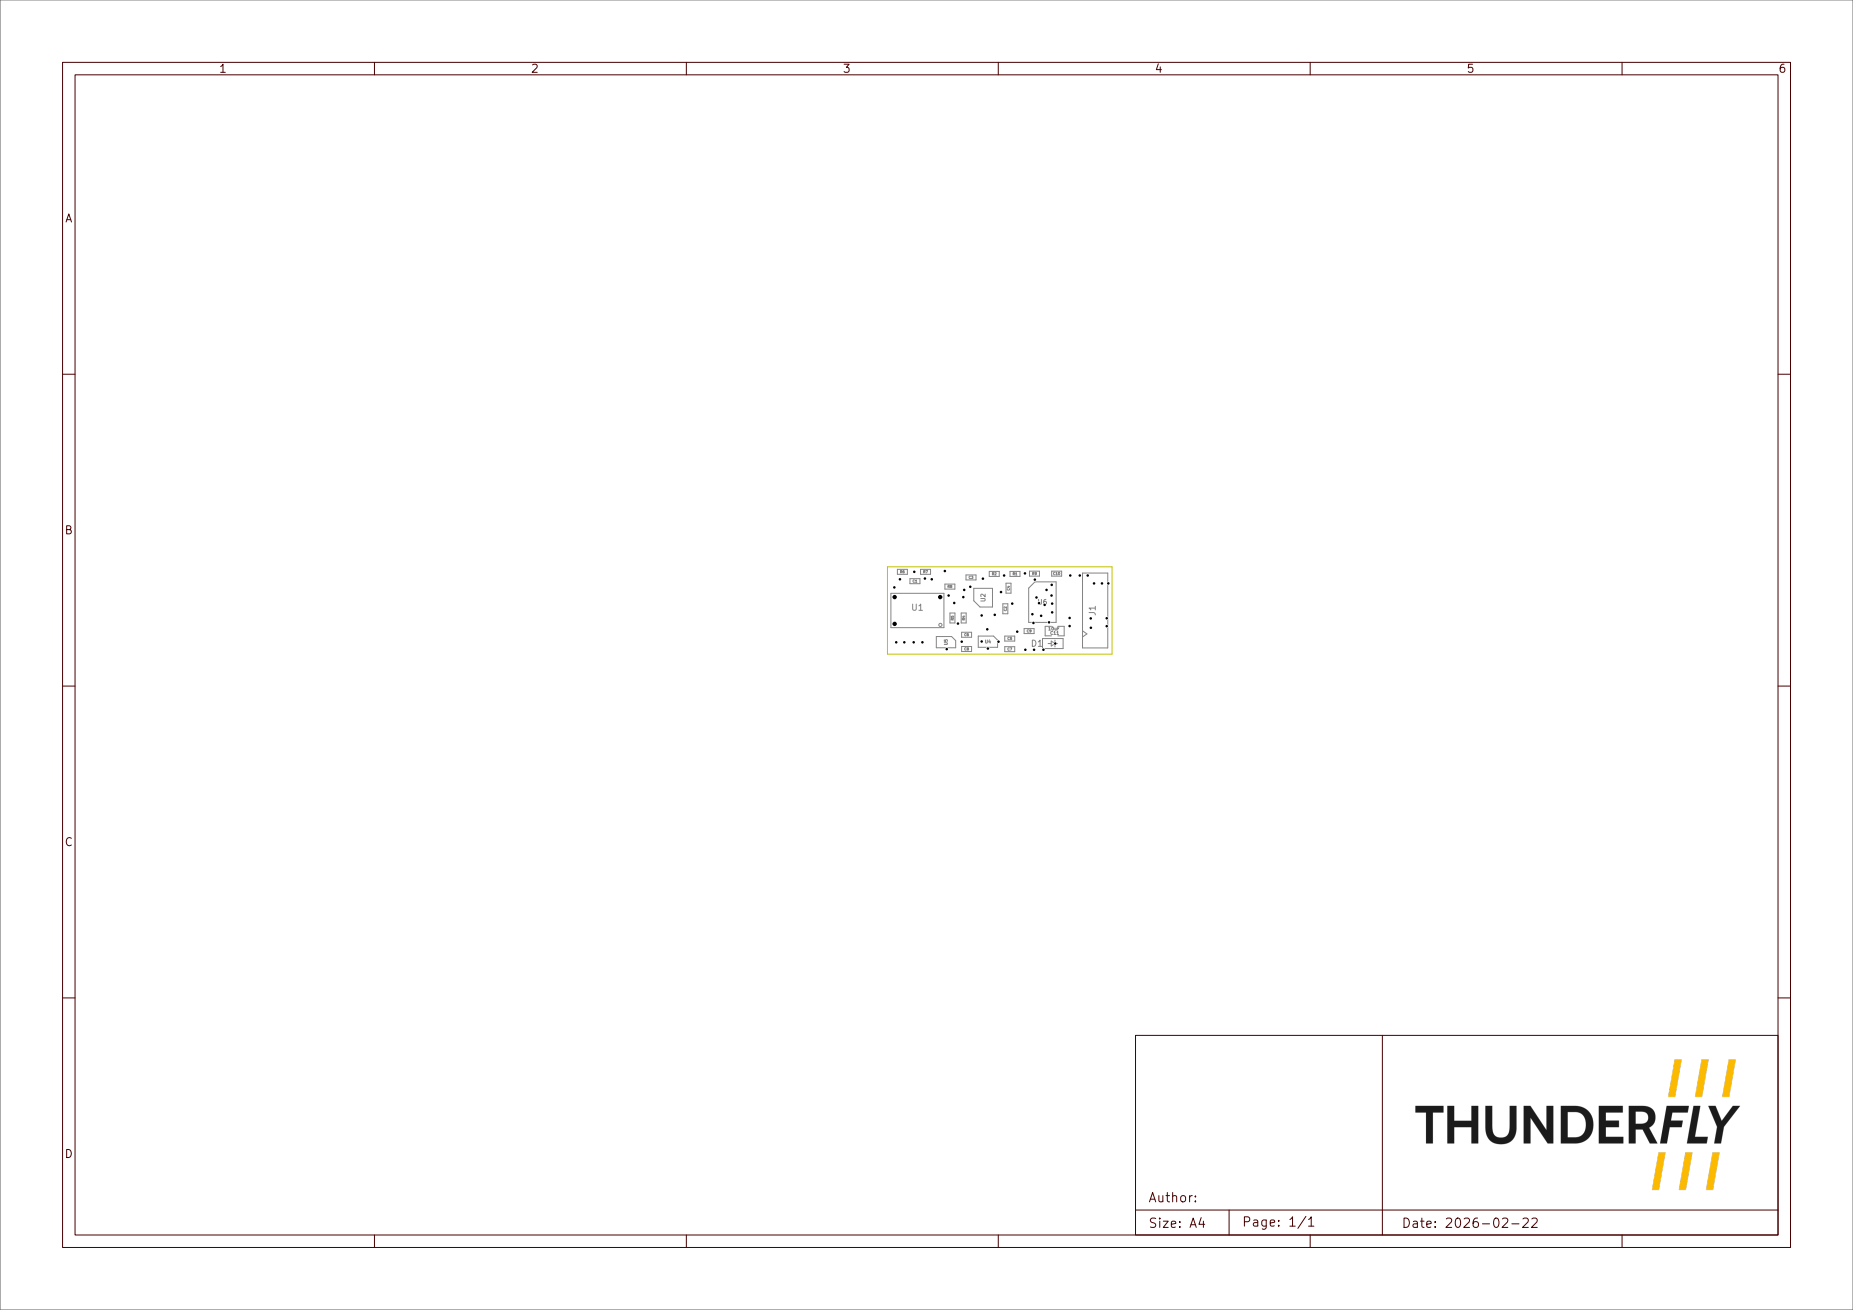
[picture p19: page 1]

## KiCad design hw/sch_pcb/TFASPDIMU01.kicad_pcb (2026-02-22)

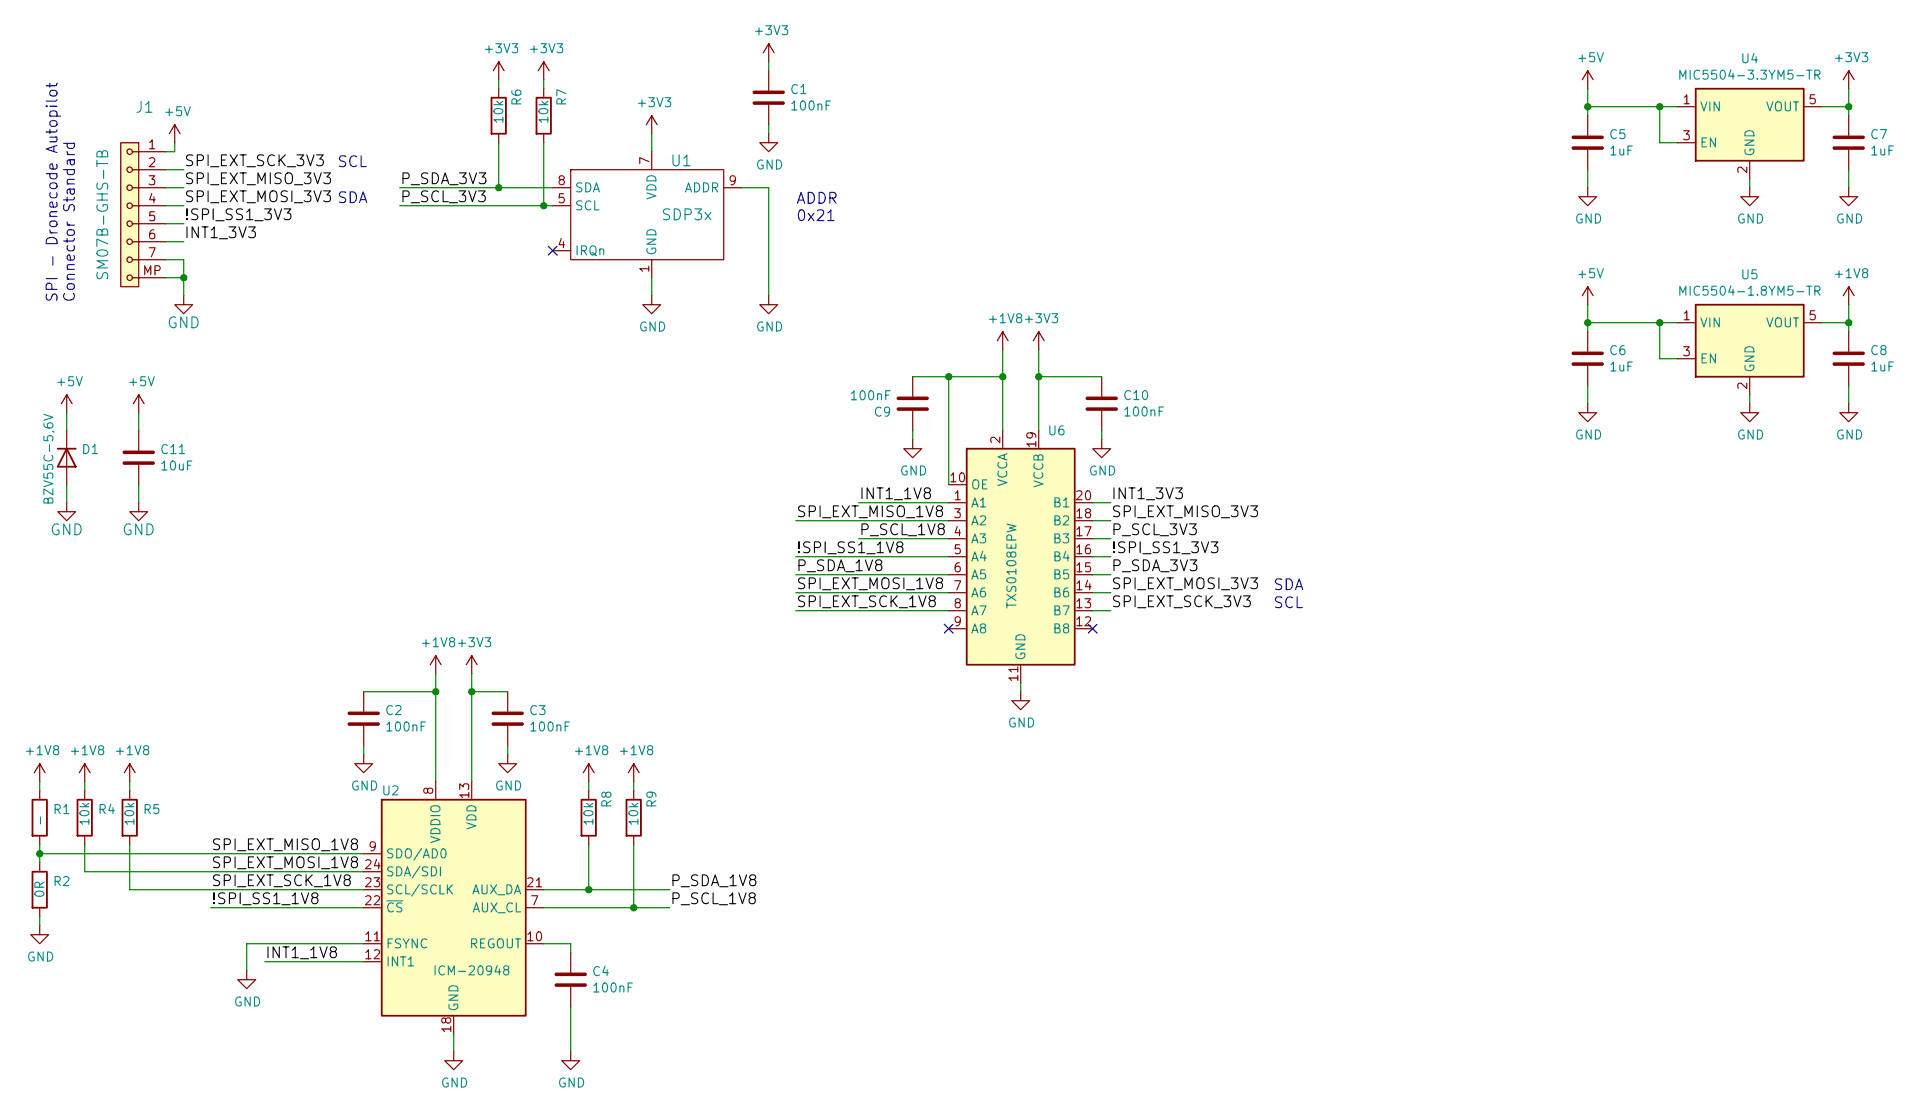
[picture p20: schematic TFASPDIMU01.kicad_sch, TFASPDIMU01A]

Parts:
C1, C2, C3, C4, C9, C10: 100nF; SMD-0603
C5, C6, C7, C8: 1uF; SMD-0603
C11: 10uF; SMD-0805
D1: BZV55C-5,6V; D_MiniMELF
J1: SM07B-GHS-TB; JST_GH_SM07B-GHS-TB_1x07-1MP_P1.25mm_Horizontal
R1: -; SMD-0603
R2: 0R; SMD-0603
R4, R5, R6, R7, R8, R9: 10k; SMD-0603
U1: SDP3x
U2: ICM-20948; InvenSense_QFN-24_3x3mm_P0.4mm
U4: MIC5504-3.3YM5-TR; SOT-23-5
U5: MIC5504-1.8YM5-TR; SOT-23-5
U6: TXS0108EPW; TSSOP-20_4.4x6.5mm_P0.65mm

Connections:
+1V8: C2.1, C8.1, C9.2, R1.1, R4.1, R5.1, R8.1, R9.1, U2.8 (VDDIO), U5.5 (VOUT), U6.2 (VCCA), U6.10 (OE)
+3V3: C1.1, C3.1, C7.1, C10.1, R6.1, R7.1, U1.7 (VDD), U2.13 (VDD), U4.5 (VOUT), U6.19 (VCCB)
+5V: C5.1, C6.1, C11.1, D1.1 (K), J1.1, U4.1 (VIN), U4.3 (EN), U5.1 (VIN), U5.3 (EN)
/!SPI_SS1_1V8: U2.22 (~CS), U6.5 (A4)
/!SPI_SS1_3V3: J1.5, U6.16 (B4)
/INT1_1V8: U2.12 (INT1), U6.1 (A1)
/INT1_3V3: J1.6, U6.20 (B1)
/P_SCL_1V8: R9.2, U2.7 (AUX_CL), U6.4 (A3)
/P_SCL_3V3: R7.2, U1.5 (SCL), U6.17 (B3)
/P_SDA_1V8: R8.2, U2.21 (AUX_DA), U6.6 (A5)
/P_SDA_3V3: R6.2, U1.8 (SDA), U6.15 (B5)
/SPI_EXT_MISO_1V8: R1.2, R2.1, U2.9 (SDO/AD0), U6.3 (A2)
/SPI_EXT_MISO_3V3: J1.3, U6.18 (B2)
/SPI_EXT_MOSI_1V8: R4.2, U2.24 (SDA/SDI), U6.7 (A6)
/SPI_EXT_MOSI_3V3: J1.4, U6.14 (B6)
/SPI_EXT_SCK_1V8: R5.2, U2.23 (SCL/SCLK), U6.8 (A7)
/SPI_EXT_SCK_3V3: J1.2, U6.13 (B7)
GND: C1.2, C2.2, C3.2, C4.2, C5.2, C6.2, C7.2, C8.2, C9.1, C10.2, C11.2, D1.2 (A), J1.7, J1.MP, R2.2, U1.1 (GND), U1.2 (GND), U1.3 (GND), U1.6 (GND), U1.9 (ADDR), U1.10 (GND), U1.11 (GND), U1.17 (GND), U1.18 (GND), U2.11 (FSYNC), U2.18 (GND), U2.20 (GND), U4.2 (GND), U5.2 (GND), U6.11 (GND)
unnamed: C4.1, U2.10 (REGOUT)

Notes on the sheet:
SDA
SCL
ADDR 0x21
SPI - Dronecode Autopilot Connector Standard

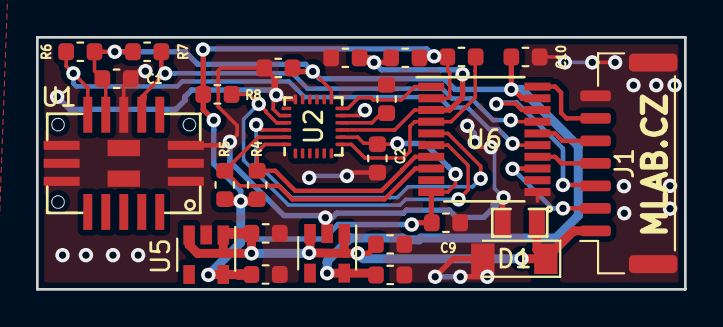
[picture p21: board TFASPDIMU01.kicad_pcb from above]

Board: 2 copper layers, 36.0 x 14.0 mm, 26 parts (0 on the bottom side), 19 nets.

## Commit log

2019-04-01 Dimensions added to PCB layout.
    [WINDGAUGE03A_PCB01A.kicad_pcb]
2020-01-25 edit description
    [WINDGAUGE03A_PCB01A.kicad_pcb, WINDGAUGE03A_PCB01A.sch]
2020-02-13 Rouding of PCB elevation to allow cable winding under the cover.
2020-04-01 Adding PCB cam files.
    [WINDGAUGE03A_PCB01A-B_Cu.gbr, WINDGAUGE03A_PCB01A-B_Mask.gbr, WINDGAUGE03A_PCB01A-Edge_Cuts.gbr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]
2020-10-29 readme of PCB
2020-10-29 zmena struktury
    [TFASPDIMU01.kicad_pcb, TFASPDIMU01.sch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]
2020-10-29 odebrani vyrobnich dat
    [WINDGAUGE03A_PCB01A-B_Cu.gbr, WINDGAUGE03A_PCB01A-B_Mask.gbr, WINDGAUGE03A_PCB01A-Edge_Cuts.gbr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]
2020-10-30 Edit PCB for 3D model
    [TFASPDIMU01.kicad_pcb]
2020-10-30 Edit schema
    [TFASPDIMU01.kicad_pcb, TFASPDIMU01.kicad_sch]
2020-11-11 Add color description of cable in the photo
2021-02-25 Schematics update.
    [TFASPDIMU01.kicad_sch, TFASPDIMU01.sch]
2021-04-05 Update title block.
    [TFASPDIMU01.kicad_sch]
2021-06-08 Improve I2C marking in schematics.
    [TFASPDIMU01.kicad_sch]
2024-06-17 Update the project to KiCAD7.
    [TFASPDIMU01.kicad_pcb, TFASPDIMU01.kicad_sch]
2024-06-17 Update actions products
    [TFASPDIMU01-B_Adhesive.dxf, TFASPDIMU01-B_Courtyard.dxf, TFASPDIMU01-B_Cu.dxf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]
2026-02-22 Cleanup and update project to KiCADv9.
    [TFASPDIMU01.kicad_pcb, TFASPDIMU01.kicad_sch]
2026-02-22 Automatic update of KiCAD outputs
    [TFASPDIMU01-B_Adhesive.dxf, TFASPDIMU01-B_Courtyard.dxf, TFASPDIMU01-B_Cu.dxf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]

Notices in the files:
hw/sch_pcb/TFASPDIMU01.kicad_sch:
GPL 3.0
